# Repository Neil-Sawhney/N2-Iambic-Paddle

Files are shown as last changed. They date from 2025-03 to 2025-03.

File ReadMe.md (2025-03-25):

# N2 Iambic Paddle - Open Source
I made this Iambic Paddle and figured i'd share it for anyone else who wants to make their own. 
Feel free to modify it as you see fit, and if you'd like to make a pull request to improve the design/documentation, feel free to do so.

The design files (SolidWorks 2022) are included in this directory as well as the STL/STEP/3MF files for 3D printing.

The [Bill of Materials](#bill-of-materials) can be found below.

# Images
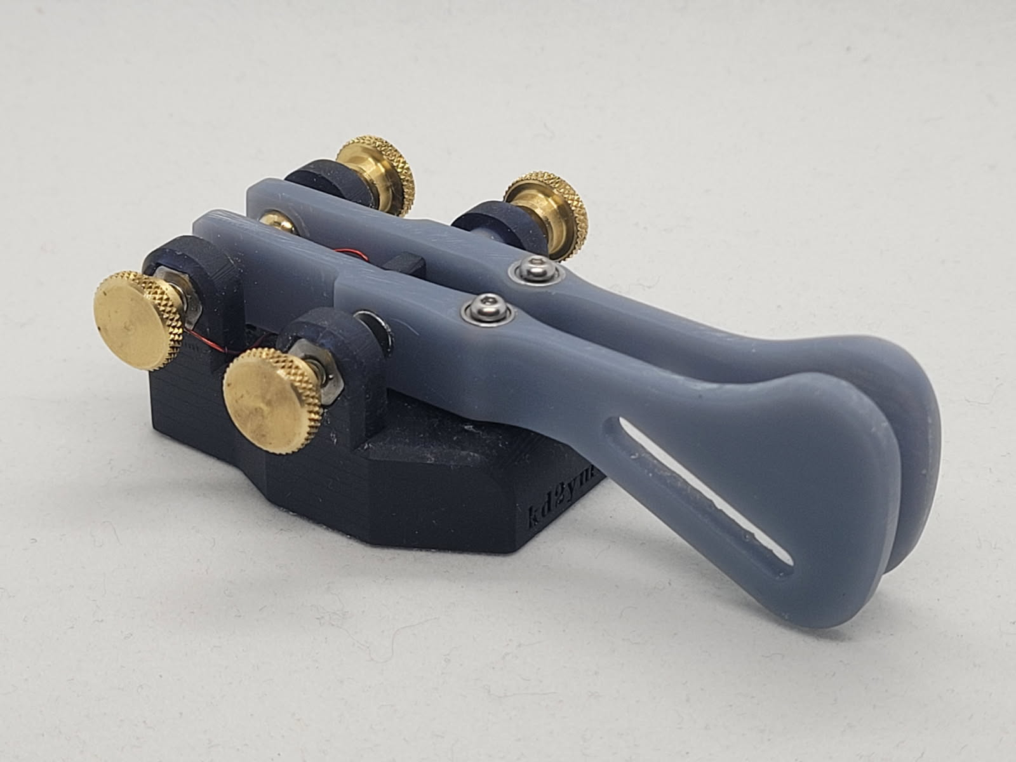
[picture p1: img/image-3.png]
side view

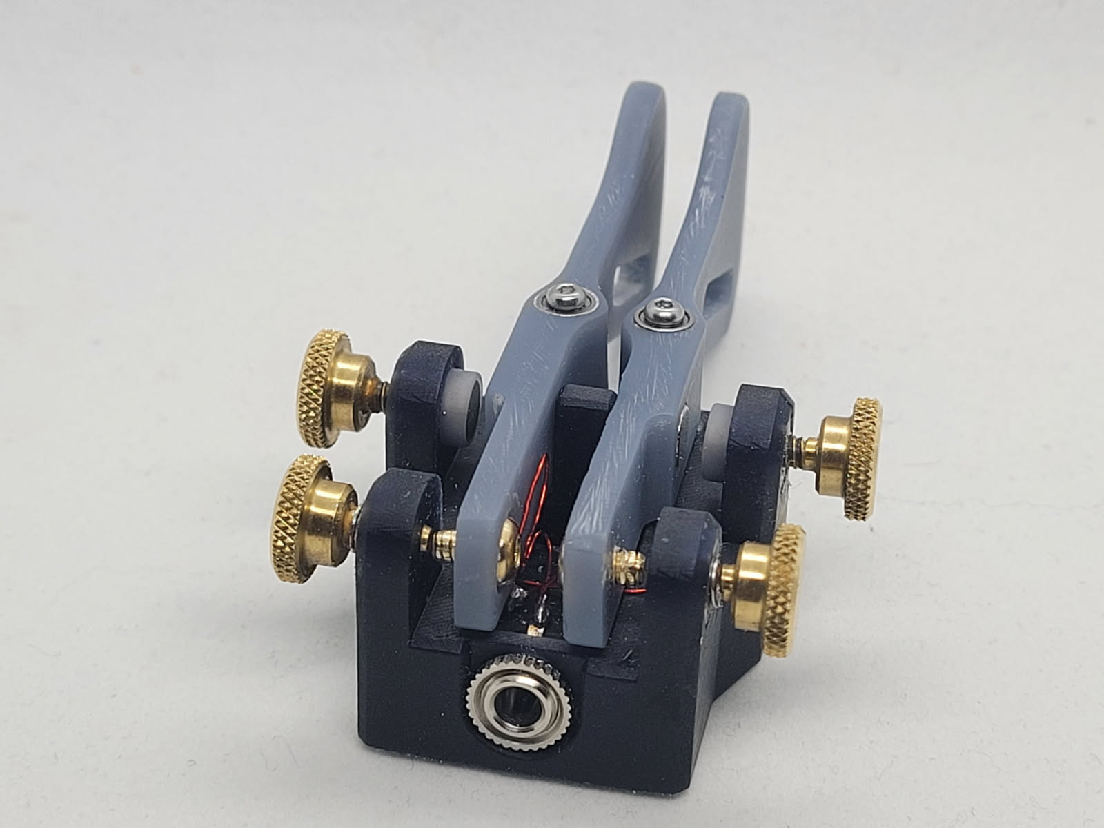
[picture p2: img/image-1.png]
back view

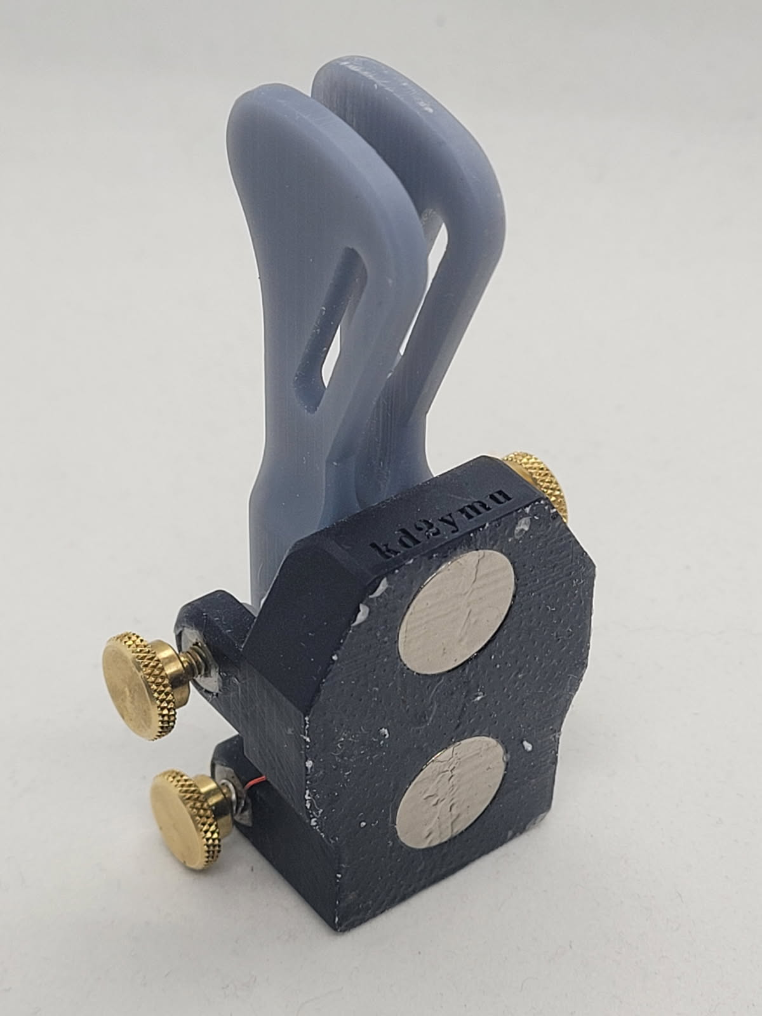
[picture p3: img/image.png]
bottom view


# Bill of Materials
All prices are referenced on 2024-03-24

Many of these compoenets can be found cheaper elsewhere or replaced with similar components.
However, this list of components is guaranteed to work as is.

| Qty | Unit | McMaster-Carr Part # | Description | Delivery | Price/Unit | Total Price |
|---|---|---|---|---|---|---|
| 1 | Pack | [92095A503](https://www.mcmaster.com/92095A503) | Button Head Hex Drive Screw Passivated 18-8 Stainless Steel, M2 x 0.40 mm Thread Size, 14 mm Long | $10.14 | $10.14 |
| 4 | Each | [98816A216](https://www.mcmaster.com/98816A216) | Brass Raised Knurled-Head Thumb Screw 4-40 Thread Size, 1/4" Long | $2.72 | $10.88 |
| 1 | Pack | [94459A120](https://www.mcmaster.com/94459A120) | Heat-Set Inserts for Plastic Brass, M2 x 0.4 mm, 4 mm Installed Length | $9.36 | $9.36 |
| 1 | Pack | [91841A005](https://www.mcmaster.com/91841A005) | 18-8 Stainless Steel Hex Nut 4-40 Thread Size | $3.69 | $3.69 |
| 1 | Each | [5734N13](https://www.mcmaster.com/5734N13) | Circuit Board Audio Equipment Connector 90 Degree Elbow Receptacle, Off, Stereo Pin Connection | $5.12 | $5.12 |
| 2 | Packs | [97715A424](https://www.mcmaster.com/97715A424) | Brass Button Head Hex Drive Screws 4-40 Thread Size, 3/16" Long | $1.97 | $3.94 |
| 2 | Each | [5862K145](https://www.mcmaster.com/5862K145) | Neodymium Magnet Magnetized Through Thickness, 1/16" Thick, 1/2" OD | $1.20 | $2.40 |
|  |  |  | **Total** |  |  | **$44.53** |

# Assembly Instructions
1. Print the parts in the STL folder
2. Glue the hex nuts into the hex nut holders on the bottom of the base.
3. Insert the heat-set inserts into the holes on the bottom of the base. (A small amount of glue may be necessary for resin prints)
4. Insert the Aux Connector into the hole on the back of the base.
5. Solder thin wires to the Aux Connector. I used magnet wire.
   - You will need to solder two wires onto the ground pin to connect to the two brass thumb screws. Refer to [Wiring Diagram](#wiring-diagram)
6. Screw all 4 brass thumb screws into the hex nuts.
7. Insert the magnets into the Magnet Screw Connectors (a small amount of glue may be necessary). Make sure the magnets are oriented correctly.
8. Screw the Magnet Screw Connectors into the two front brass thumb screws.
9. Wrap the two wires connected to ground around the back two brass thumb screws (make sure the metal is exposed and creates a nice contact), or solder them to the hex nuts.
10. Insert the bearings into the paddle arms.
11. Glue the magnets into the paddle arms. Make sure the magnets are oriented correctly.
12. Screw in the back brass screw to the back of the paddle arms halfway.
13. Wrap the dah and dit wires shown in the [Wiring Diagram](#wiring-diagram) around the respective brass screws and tighten them down. Make sure the metal is exposed and creates a nice contact.
14. Screw the paddle arms into the base.
15. Glue the two neodymium magnets into the slots on the bottom of the base. Make sure the magnets are oriented correctly.
15. Test the paddle to make sure it works correctly.
16. Enjoy!

## Wiring Diagram
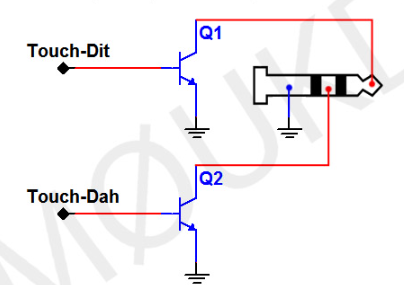
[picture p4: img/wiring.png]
Wiring Diagram


## Tips and Tricks
I applied a thin layer of E6000 glue to the bottom of the base to give it some grip on the table. This is optional but I found it to be helpful to prevent the paddle from sliding around.

I also applied some thread lock to the brass thumb screws to prevent them from moving, which allows for finer adjustment of the paddle tension and spacing.

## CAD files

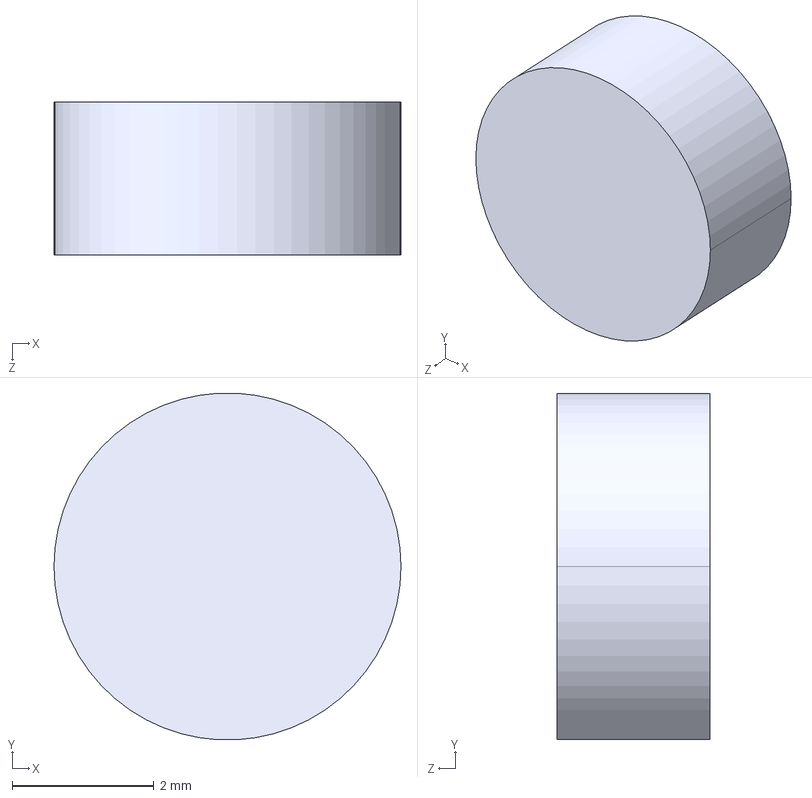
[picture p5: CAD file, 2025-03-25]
step/Magnet^iambic_paddle.STEP
4.90 x 4.89 x 2.16 mm

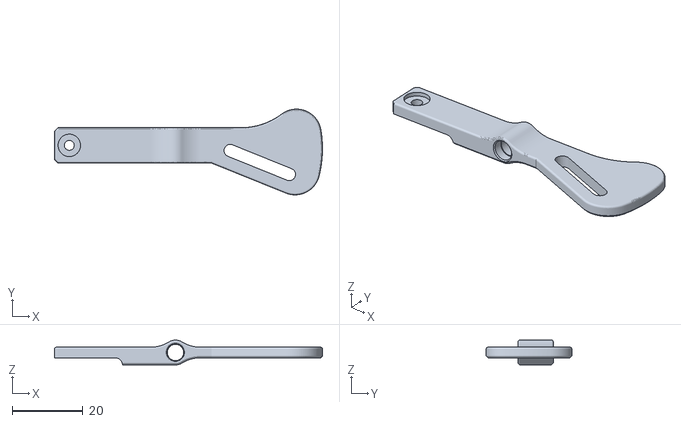
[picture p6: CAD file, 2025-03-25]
stl/iambic_paddle - MirrorIambic_LHS^iambic_paddle-2.STL
75.7 x 24.2 x 7.02

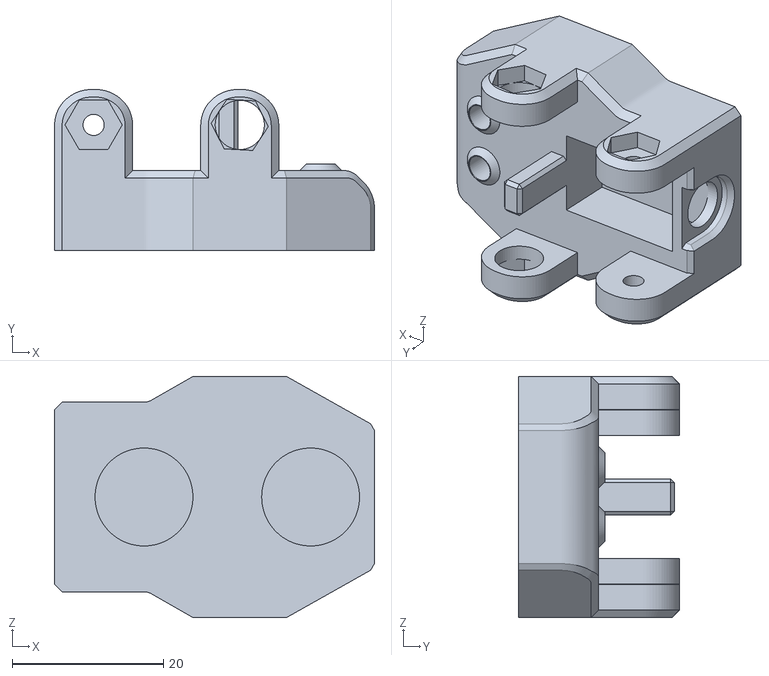
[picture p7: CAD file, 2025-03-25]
stl/iambic_paddle - case^iambic_paddle-1.STL
42.3 x 21.3 x 31.9

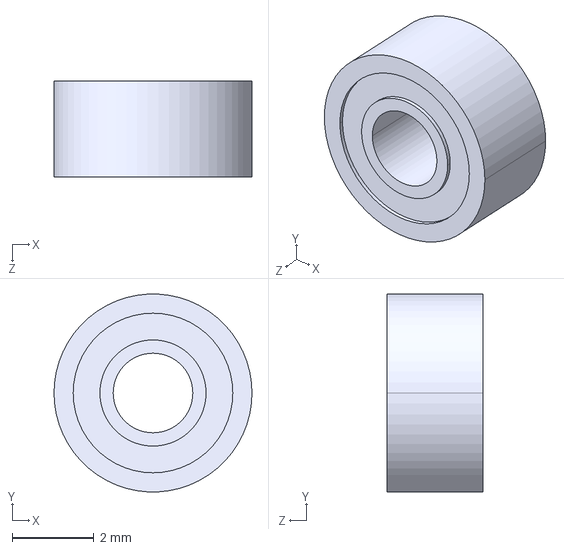
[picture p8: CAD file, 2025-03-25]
step/bearing^iambic_paddle.STEP
4.85 x 4.84 x 2.35 mm

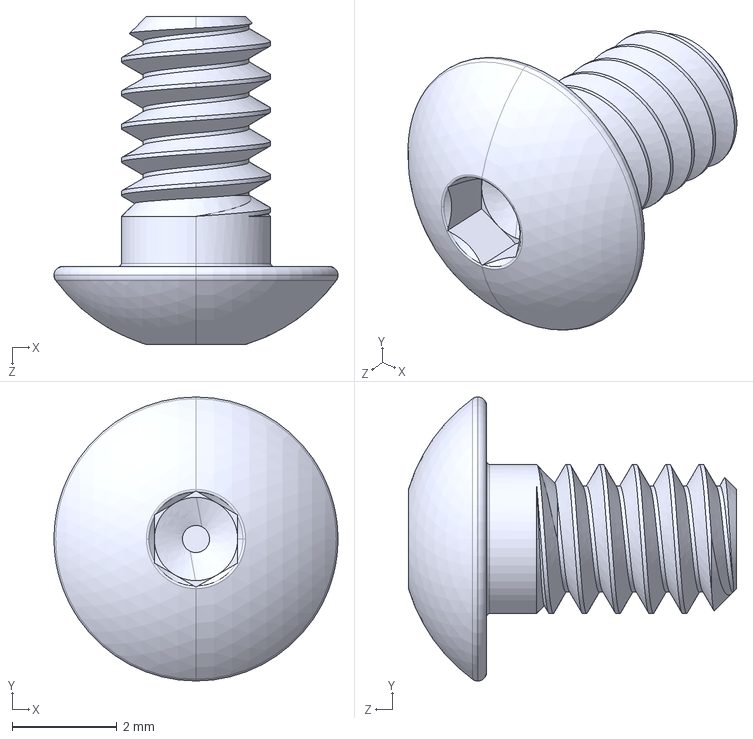
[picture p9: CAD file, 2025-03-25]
step/97715A424_Brass Button Head Hex Drive Screws(2)_97715A424.STEP
5.41 x 5.41 x 6.25 mm

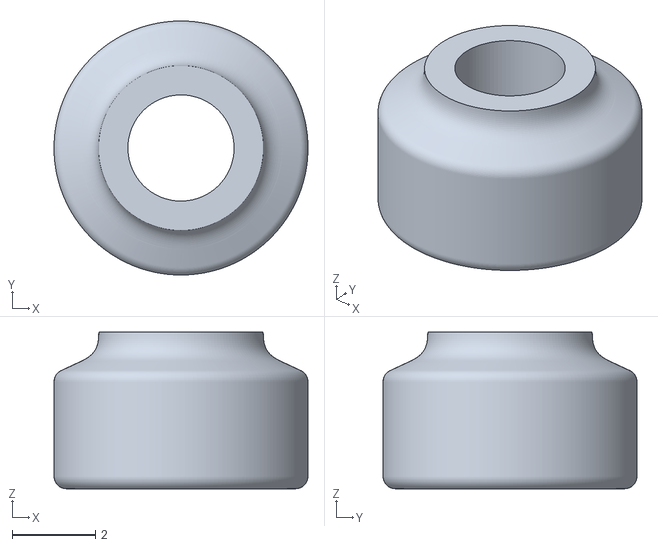
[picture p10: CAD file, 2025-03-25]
stl/iambic_paddle - maget_screw_connector^iambic_paddle-1.STL
6.10 x 6.10 x 3.76

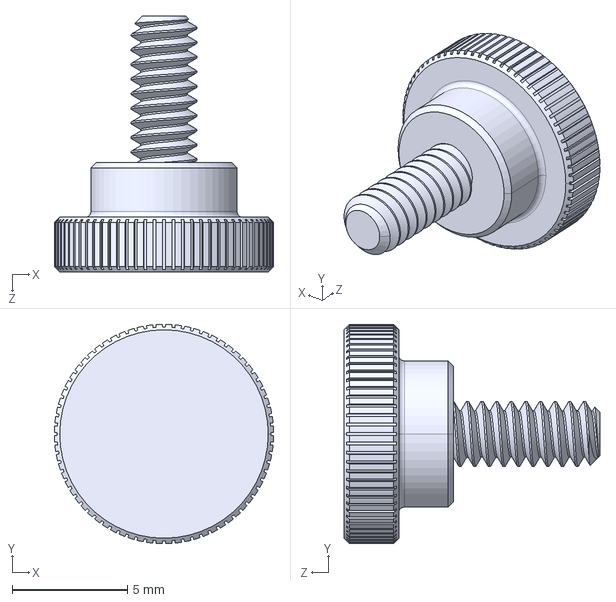
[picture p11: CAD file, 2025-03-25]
step/98816A216_Brass Raised Knurled-Head Thumb Screw_98816A216.STEP
9.52 x 9.52 x 11.1 mm

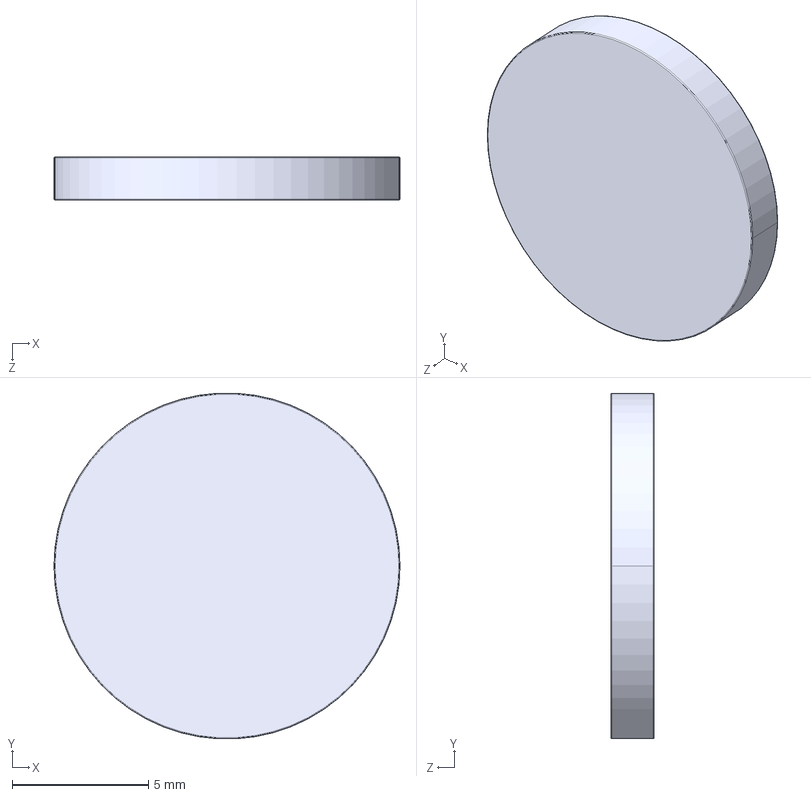
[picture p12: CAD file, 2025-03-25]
step/5862K145_Neodymium Magnet_5862K145.STEP
12.7 x 12.7 x 1.59 mm

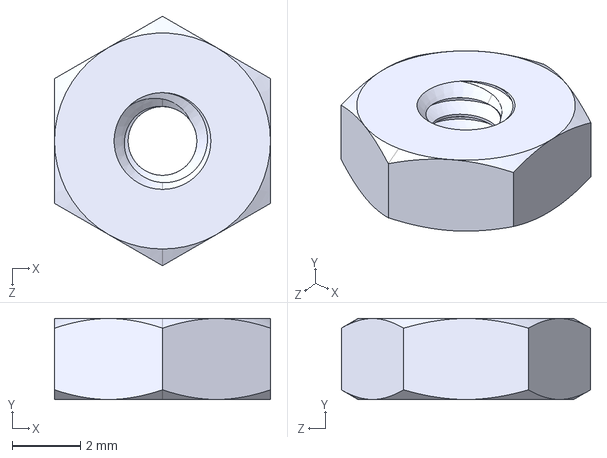
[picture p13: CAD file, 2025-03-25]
step/91841A005_18-8 Stainless Steel Hex Nut_91841A005.STEP
6.35 x 2.38 x 7.33 mm

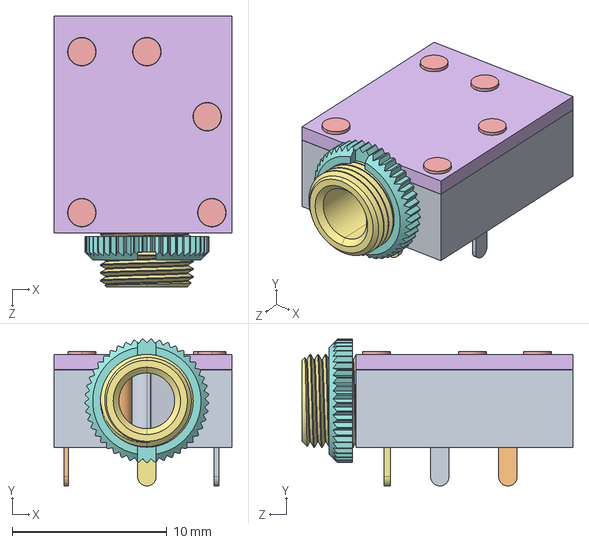
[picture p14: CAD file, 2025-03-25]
step/5734N13_Circuit Board Audio Equipment Connector_5734N13.STEP
11.5 x 9.49 x 17.5 mm

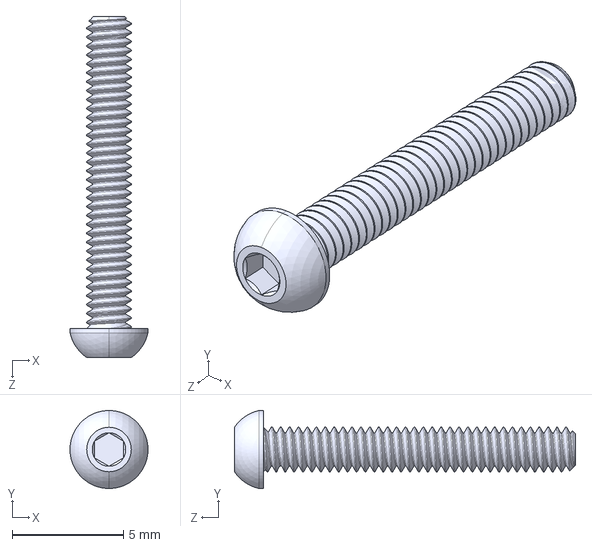
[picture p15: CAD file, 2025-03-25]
step/92095A503_Button Head Hex Drive Screw_92095A503.STEP
3.50 x 3.50 x 15.3 mm

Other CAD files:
stl/iambic_paddle - Iambic_LHS^iambic_paddle-1.STL
step/iambic_paddle.STEP
step/Iambic_LHS^iambic_paddle.STEP
step/MirrorIambic_LHS^iambic_paddle.STEP
step/case^iambic_paddle.STEP
stl/iambic_paddle - maget_screw_connector^iambic_paddle-2.STL
step/maget_screw_connector^iambic_paddle.STEP
3mf/iambic_paddle.3MF
step/94459A120_Heat-Set Inserts for Plastic_94459A120.STEP
